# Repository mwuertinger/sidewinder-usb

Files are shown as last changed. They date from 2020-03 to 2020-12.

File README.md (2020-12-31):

# sidewinder-usb
This repository contains hard- and software for building a USB adapter for the
[MS SideWinder 3D Pro](https://en.wikipedia.org/wiki/Microsoft_SideWinder#3D_Pro) joystick.

The joystick uses a proprietary protocol over the analg gameport which makes it impossible to use
standard off the shelf gameport USB adapters. The protocol works by sending a state vector over the
three button lines of the gameport. There is no analog transmission taking place. More details can
be found in [US patent 5628686A](https://patents.google.com/patent/US5628686A/en) or in the [Linux
driver](https://github.com/torvalds/linux/blob/master/drivers/input/joystick/sidewinder.c)
implementation.

## Software
The software is taken from [sw3dprousb](https://code.google.com/archive/p/sw3dprousb) with
permission from the [author](mailto:detlef@gmail.com). All credit regarding the software goes to the
original author.

The ATmega32u4 controller comes with a pre-configured bootloader which is
[DFU](https://en.wikipedia.org/wiki/USB#Device_Firmware_Upgrade) compatible. This allows to flash
the firmware via USB without the need for an
[ICSP](https://en.wikipedia.org/wiki/In-system_programming) port.

The [flash-firmware.sh](/flash-firmware.sh) script can be used to flash the firmware
on a newly assembled board using the [dfu-programmer](https://dfu-programmer.github.io/) utility.
This should work out of the box on Linux systems provided that there is only one DFU device present.

## Hardware
The hardware is based on a minimal design around the ATmega32u4 microcontroller and follows the
suggestions from the sw3dprousb project as well as from
[this DescentBB thread](https://www.descentbb.net/viewtopic.php?t=15526).

### Schematic
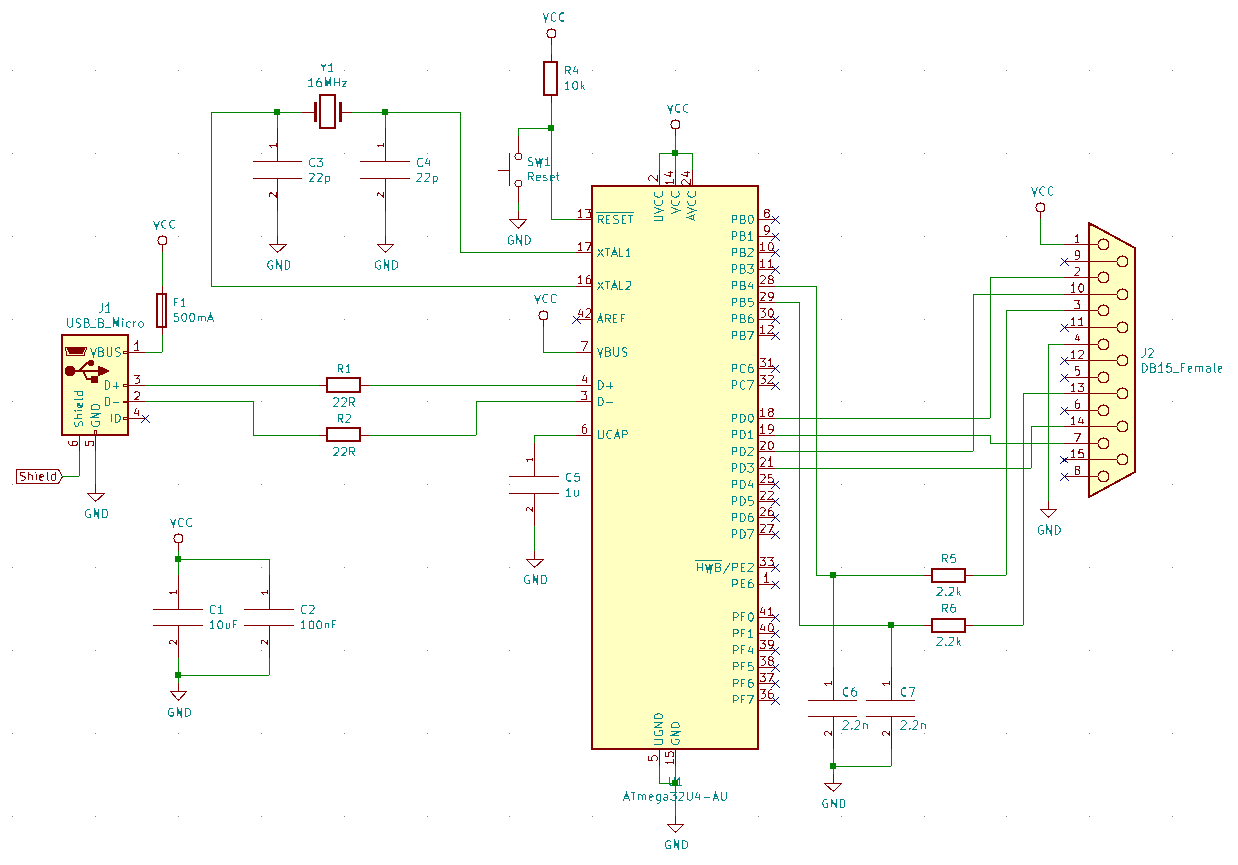
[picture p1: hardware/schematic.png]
Schematic


### Board Layout
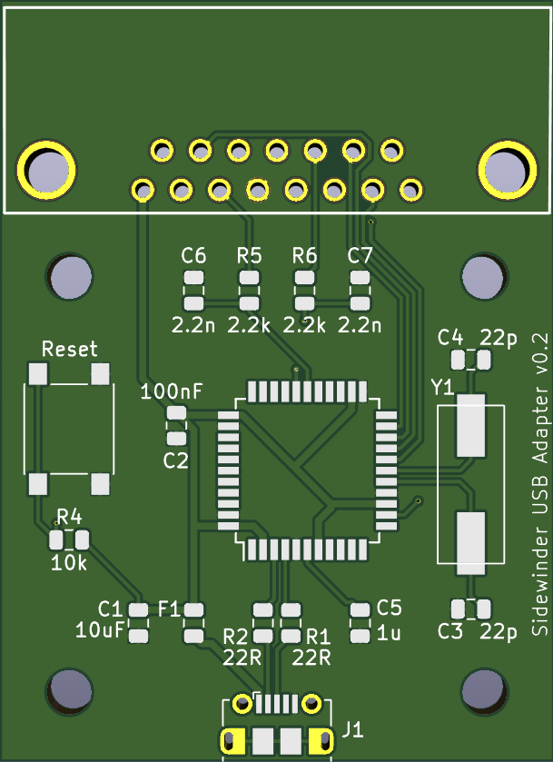
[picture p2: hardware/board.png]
Board


### Picture of an assembled v0.2 board
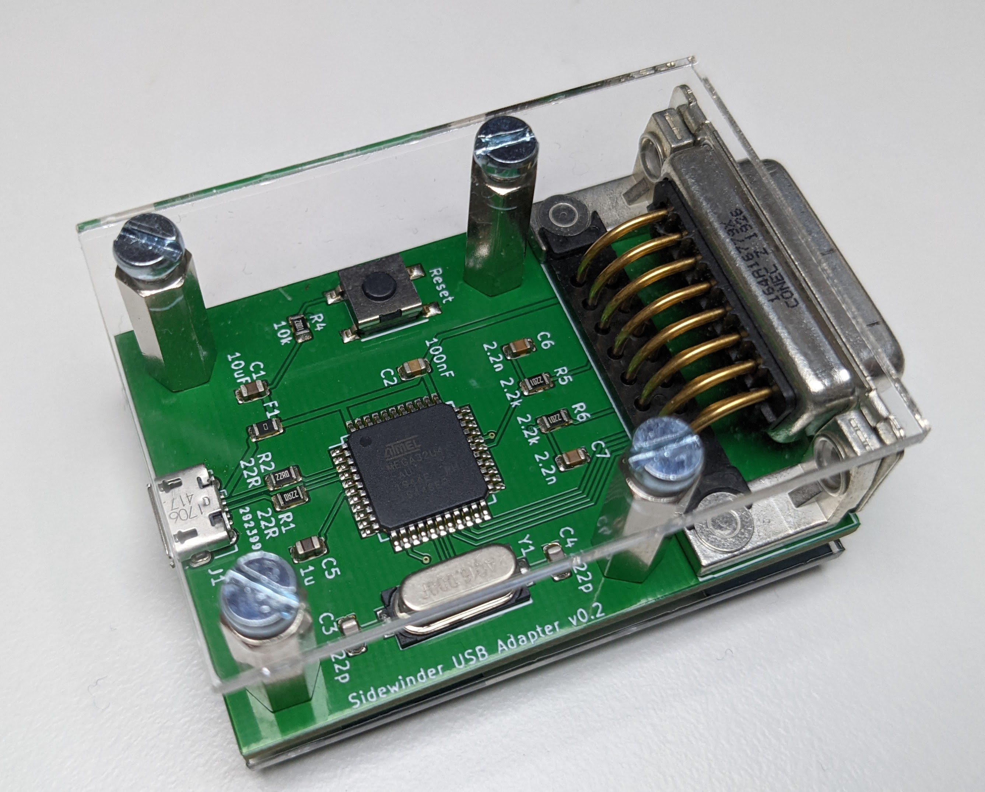
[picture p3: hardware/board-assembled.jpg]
Assembled


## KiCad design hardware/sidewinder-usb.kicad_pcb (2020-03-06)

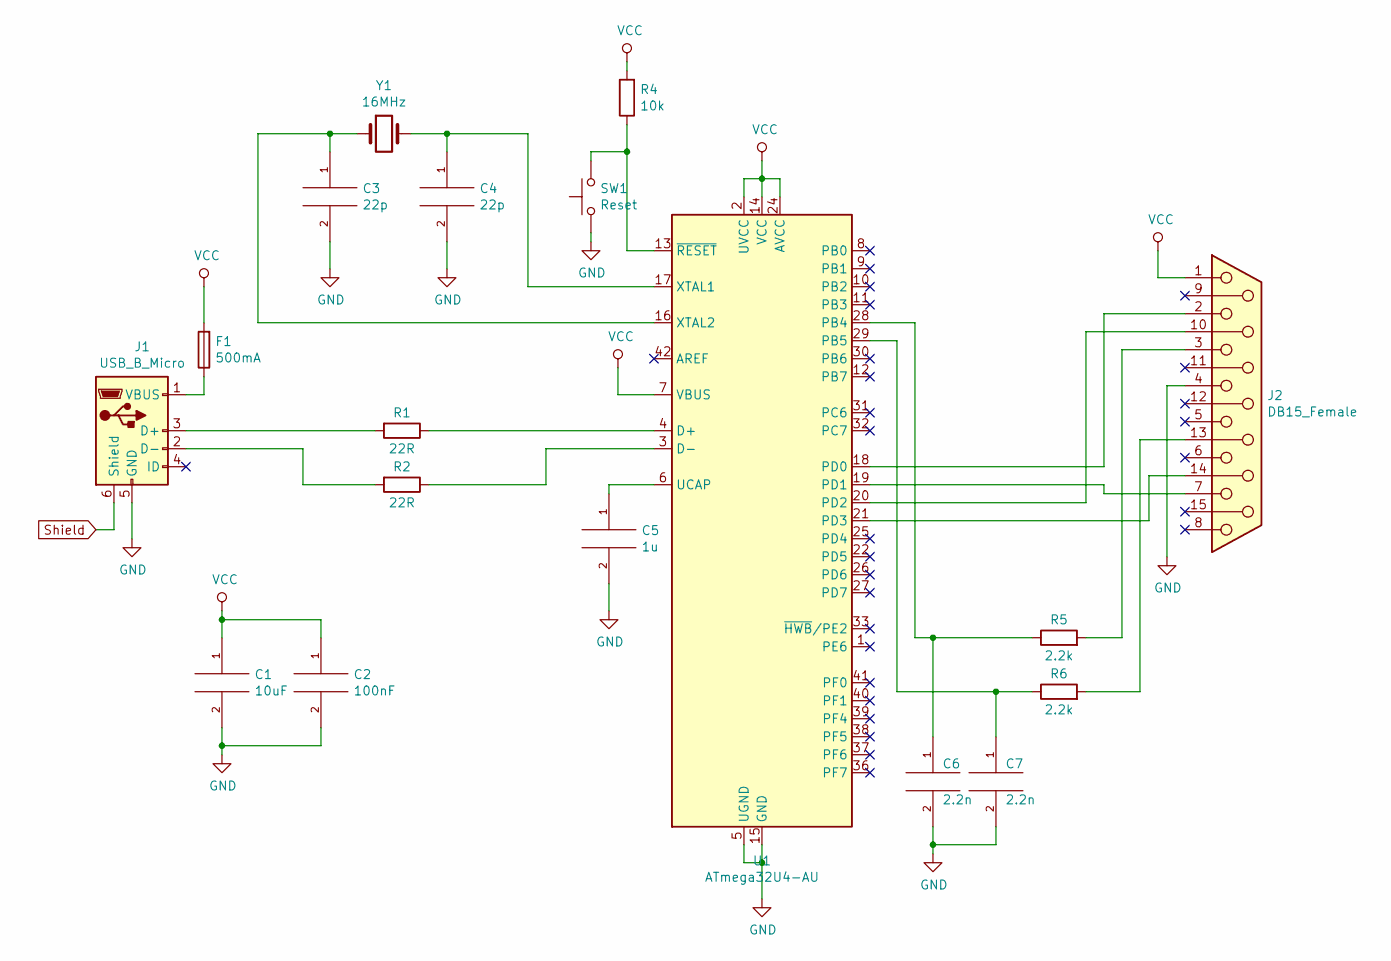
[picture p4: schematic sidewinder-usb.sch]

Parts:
C1: 10uF; C_0805_2012Metric
C2: 100nF; C_0805_2012Metric
C3, C4: 22p; C_0805_2012Metric
C5: 1u; C_0805_2012Metric
C6, C7: 2.2n; C_0805_2012Metric
F1: 500mA; Fuse_0805_2012Metric
J1: USB_B_Micro; USB_Micro-B_Molex-105017-0001
J2: DB15_Female; 618015233821
R1, R2: 22R; R_0805_2012Metric
R4: 10k; R_0805_2012Metric
R5, R6: 2.2k; R_0805_2012Metric
SW1: Reset; SW_Push_1P1T_NO_6x6mm_H9.5mm
U1: ATmega32U4-AU; TQFP-44_10x10mm_P0.8mm
Y1: 16MHz; Auris_HC49USSMD

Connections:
GND: C1.2, C2.2, C3.2, C4.2, C5.2, C6.2, C7.2, J1.5 (GND), J2.4, SW1.1, U1.5 (UGND), U1.15 (GND), U1.23 (GND), U1.35 (GND), U1.43 (GND)
unnamed: C3.1, U1.16 (XTAL2), Y1.1
unnamed: C4.1, U1.17 (XTAL1), Y1.2
unnamed: C5.1, U1.6 (UCAP)
unnamed: C6.1, R5.1, U1.28 (PB4)
unnamed: C7.1, R6.1, U1.29 (PB5)
unnamed: F1.1, J1.1 (VBUS)
unnamed: J1.2 (D-), R2.2
unnamed: J1.3 (D+), R1.2
unnamed: J2.2, U1.18 (PD0)
unnamed: J2.3, R5.2
unnamed: J2.7, U1.19 (PD1)
unnamed: J2.10, U1.20 (PD2)
unnamed: J2.13, R6.2
unnamed: J2.14, U1.21 (PD3)
unnamed: R1.1, U1.4 (D+)
unnamed: R2.1, U1.3 (D-)
unnamed: R4.1, SW1.2, U1.13 (~RESET)
Shield: J1.6 (Shield), J2.S1, J2.S2
VCC: C1.1, C2.1, F1.2, J2.1, R4.2, U1.2 (UVCC), U1.7 (VBUS), U1.14 (VCC), U1.24 (AVCC), U1.34 (VCC), U1.44 (AVCC)

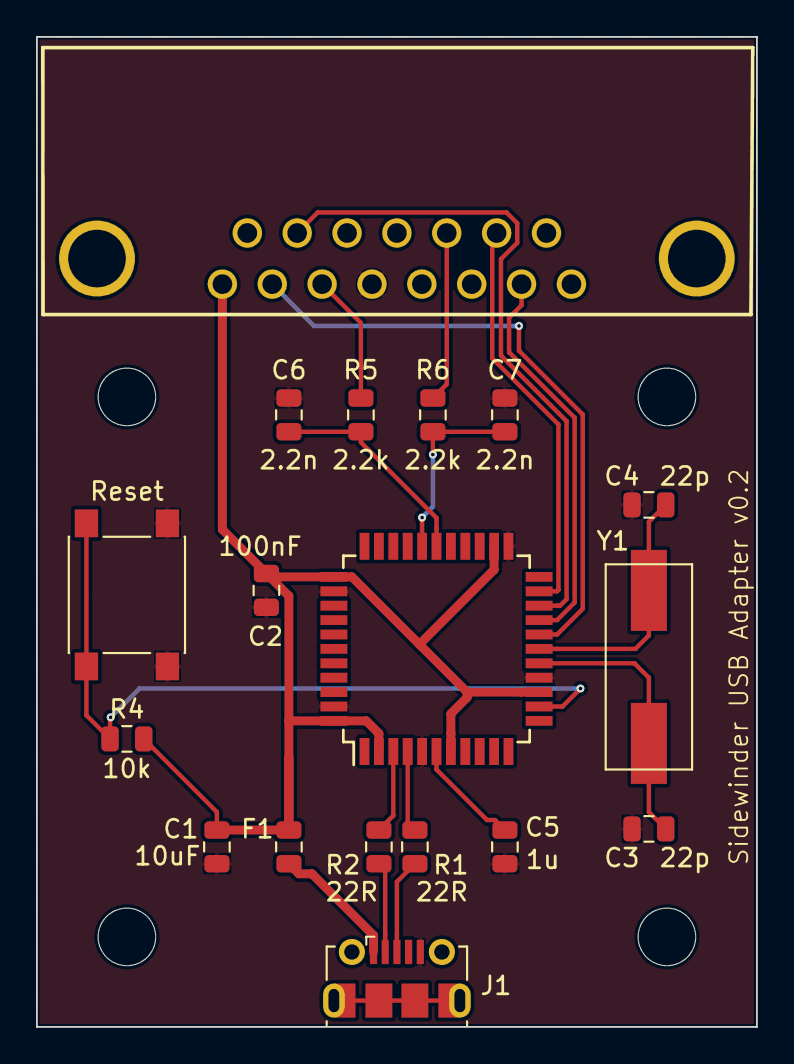
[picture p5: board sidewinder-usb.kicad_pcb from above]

Board: 2 copper layers, 40.0 x 55.0 mm, 18 parts (0 on the bottom side), 20 nets.

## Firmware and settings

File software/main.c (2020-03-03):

/*******************************************************************************
 * File Name	: main.c
 * Project	: 3DP-Vert, Microsoft Sidewinder 3D Pro/PP/FFP to USB converter
 * Date		: 2006/12/15, 2008/02/12, 2009/06/26
 * Version	: 4.0
 * Target MCU	: AT90USB162/AT90USB82, ATMEGA16U4/ATMEGA32U4
 * Tool Chain	: Atmel AVR Studio 4.17 666 / WinAVR 20090313
 * Author	: Detlef "Grendel" Mueller
 *		  detlef@gmail.com
 * References	:
 * Description	: USB to 3D Pro converter main program
 * Device	: Microsoft SideWinder 3D Pro, Precision Pro, Force Feedback Pro
 *
 * Release Notes:
 *
 * $Id: main.c 1.7 2010/04/23 05:32:26 Detlef Exp Detlef $
 ******************************************************************************/

#include "3DPro.h"
#include "usb_hid.h"

//------------------------------------------------------------------------------
// Delay until reading stick after last report was sent

 #define READ_DEL	MS2TM( 3, 1024 )
 #define IDLE_DEL	MS2TM( 4  , 64 )

//------------------------------------------------------------------------------

uint8_t
    sw_reportsz ;				// Size of SW report in bytes

uint8_t
    idle_rate,					// idle rate in 4ms clicks, 0 for indefinite
    idle_cnt,					// idle timer (count down)
    sw_repsav[SW_REPSZ_3DP] ;			// USB report data saved

//------------------------------------------------------------------------------
// Watchdog is not turned off by a reset, see avr-libc's wdt.h documentation

// uint8_t VA_NOINIT( mcusr_cpy ) ;

void FA_INIT3( Init3 ) ( void )
{
//  mcusr_cpy = MCUSR ;				// If we need to examine reset reason
    MCUSR = 0 ;
    wdt_disable() ;
}

//------------------------------------------------------------------------------
// Check if current report differs from the last saved one and save it.

static uint8_t sw_repchg ( void )
{
    uint8_t
	r = FALSE,
	i = sw_reportsz ;

    for ( ; i-- ; )
	if ( sw_repsav[i] != sw_report[i] )
	{
	    sw_repsav[i] = sw_report[i] ;
	    r = TRUE ;
	}

    return ( r ) ;
}

//------------------------------------------------------------------------------

int FA_NORETURN( main ) ( void )
{
    uint16_t
	timer ;
    uint8_t
	susp,
	sw_sendrep ;

    // Initialize..

    init_hw() ;					// hardware.

    sw_reportsz =				// report size
	(sw_id == SW_ID_3DP ? SW_REPSZ_3DP : SW_REPSZ_FFP) ;

    usb_init() ;				// USB stack

    sei() ;					// Enable interrupts

    SetTMPS( 1, 64 ) ;				// Set T1 prescaler to /64
    SetTMPS( 0, 1024 ) ;			// Set T0 prescaler to / 1024 for delay

    susp = TRUE ;
    sw_sendrep = sw_repchg() ;			// Init send report flag, saved report
    timer = 0 ;

    for ( ;; )					// Forever..
    {
	wdt_reset() ;				// Calm watchdog

	if ( usb_configured() )
	{
	    if ( susp )				// Coming out of suspend
	    {
		susp = FALSE ;

		// Turn things back on

		// Set clock divider to 1, full speed
		clock_prescale_set( clock_div_1 ) ;

		clr_bits( PRR0, _BV(PRTIM0) | _BV(PRTIM1) ) ;

		idle_cnt = idle_rate ;		// reset idle counter

		ResetTM( 0, READ_DEL ) ;
		ResetTM( 1, IDLE_DEL ) ;

		wdt_enable( WDTO_500MS ) ;	// Unleash watchdog
	    }

	    if ( TMexp( 0 ) )			// Time to read the stick
	    {
		SetTMPS( 0, 64 ) ;		// Set T0 prescaler to / 64 for query
		getdata() ;			// read 3DP data

		SetTMPS( 0, 1024 ) ;		// Set T0 prescaler to / 1024 for delay
		ResetTM( 0, READ_DEL ) ;

		if ( sw_repchg() )		// Report changed,
		    sw_sendrep = TRUE ;		// need to send it
	    }

	    if ( TMexp( 1 ) )			// Idle timed out
	    {
		ResetTM( 1, IDLE_DEL ) ;

		if ( ! --idle_cnt && idle_rate )// Idle counter expired, rate not indef.
		    sw_sendrep = TRUE ;		// need to send current report
	    }

	    if ( sw_sendrep && ! usb_IN_busy() )
	    {
		LED_on() ;
						// Send report
		usb_send_IN( sw_report, sw_reportsz ) ;

		sw_sendrep = FALSE ;		// reset send report flag
		idle_cnt   = idle_rate ;	// reset idle counter
		ResetTM( 1, IDLE_DEL ) ;	// reset idle timer

		LED_off() ;
	    }
	}
	else
	if ( usb_suspend )
	{
	    if ( ! susp )			// Going into suspend
	    {
		susp = TRUE ;

		// Shut down things we don't need

		wdt_disable() ;

		set_bits( PRR0, _BV(PRTIM0) | _BV(PRTIM1) ) ;

		// Set clock divider to 2, half speed

		clock_prescale_set( clock_div_2 ) ;

		timer    = 0xFFFF ;
		idle_cnt = 10 ;
	    }

	    if ( ! --timer )
	    {
		timer = 0xFFFF ;

		if ( ! --idle_cnt )
		{
		    if ( LED_sts() )
		    {
			timer    = 0xFFFF ;
			idle_cnt = 10 ;
			LED_off() ;
		    }
		    else
		    {
			timer    = 30 ;
			idle_cnt = 1 ;
			LED_on() ;
		    }
		}
	    }
	}
	else
	{
	    ResetTM( 1, IDLE_DEL ) ;		// reset idle timer
	    ResetTM( 0, READ_DEL ) ;		// reset SW timer
	}
    }
}

//------------------------------------------------------------------------------

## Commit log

2020-03-03 Embed schematic.png in README.md
2020-03-03 Add board images
2020-03-06 KiCad Design
    [sidewinder-usb-B_Cu.gbr, sidewinder-usb-B_Mask.gbr, sidewinder-usb-B_Paste.gbr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]
2020-03-06 Final design for v0.2
    [sidewinder-usb-B_Cu.gbr, sidewinder-usb-B_Mask.gbr, sidewinder-usb-B_Paste.gbr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]
2020-03-06 Clean up folder structure
    [sidewinder-usb-B_Cu.gbr, sidewinder-usb-B_Mask.gbr, sidewinder-usb-B_SilkS.gbr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]
2020-03-06 Add schematic and board screenshots
2020-09-20 Add XML file and gerber.zip
2020-09-20 Add acryl case design file
2020-12-31 Replace image of assembled board
